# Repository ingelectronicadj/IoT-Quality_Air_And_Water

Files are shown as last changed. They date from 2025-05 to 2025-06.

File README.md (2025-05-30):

# Proyecto de Monitoreo de Calidad del Agua y del Aire con NodeMCU ESP8266

## Descripción

Este proyecto consiste en un sistema de monitoreo básico de **calidad del agua** y **calidad del aire** utilizando una placa **NodeMCU ESP8266**. Se integran sensores para medir:

- **TDS (Total de Sólidos Disueltos)** en el agua.
- **Compuestos orgánicos volátiles (TVOC)** y **dióxido de carbono equivalente (eCO2)** mediante el sensor **SGP30**.
- **Temperatura y humedad relativa** mediante un sensor **DHT11** usado para realizar compensación de la medición de TDS y por calculo realizar compensación de TVOC y eCO2 con humedad absoluta.

Los datos se envían a la plataforma en la nube **[Blynk](https://blynk.io/)** para su visualización en tiempo real desde dispositivos móviles o paneles web.

---

## Componentes del Sistema

| Componente | Descripción |
|---|---|
| **NodeMCU ESP8266** | Microcontrolador con conectividad WiFi integrada, ideal para IoT |
| **Sensor TDS (DFRobot)** | Sensor para medir sólidos disueltos totales (TDS) en agua |
| **Sensor DHT11** | Sensor digital de temperatura y humedad relativa |
| **Sensor SGP30** | Sensor de gas para medir eCO₂ (CO₂ equivalente) y TVOC |
| **Resistencia 10kΩ** | Resistencia pull-up para el pin de datos del sensor DHT11 |
| **Protoboard** | Tablero de pruebas sin soldadura para prototipado rápido |
| **Cables Dupont** | Cables macho-macho / macho-hembra para realizar conexiones entre componentes |
| **Adaptador de voltaje** | Módulo step-up o cargador que regula la salida a 5V |
| **Batería recargable** | Fuente de energía portátil para alimentar el sistema en campo |

---

## Esquemas

_A continuación se muestra el diagrama de conexiones físicas y de funcionamiento del proyecto:_

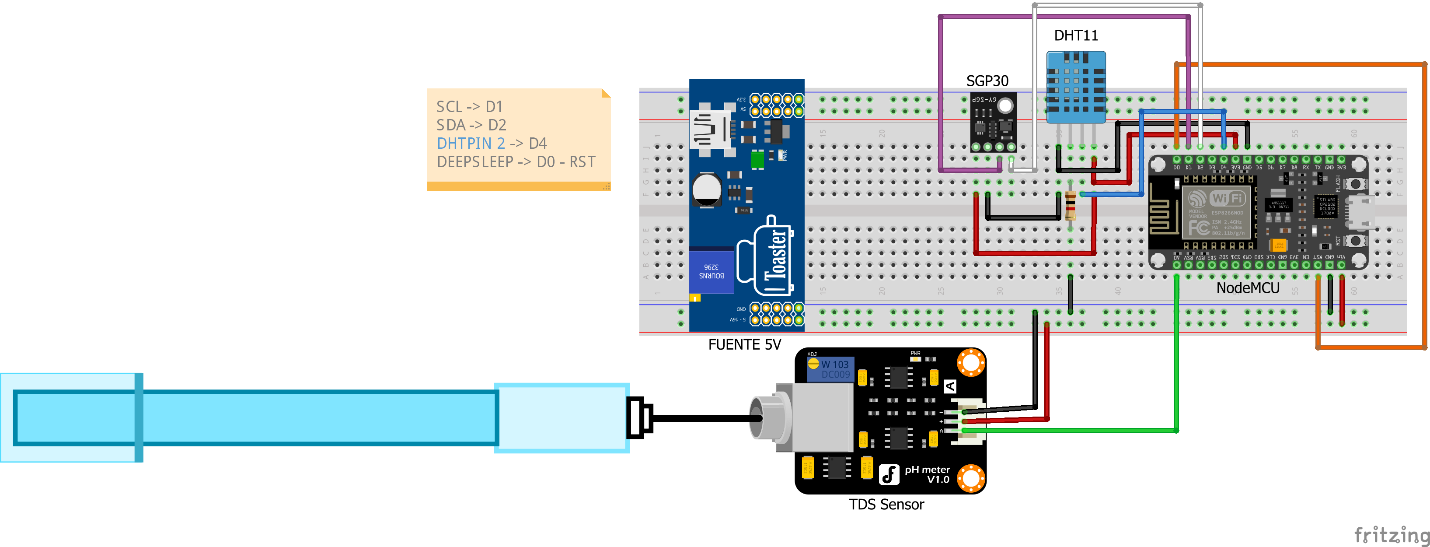
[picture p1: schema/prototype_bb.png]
Esquema de conexión


_Esquema de funcionamiento:_

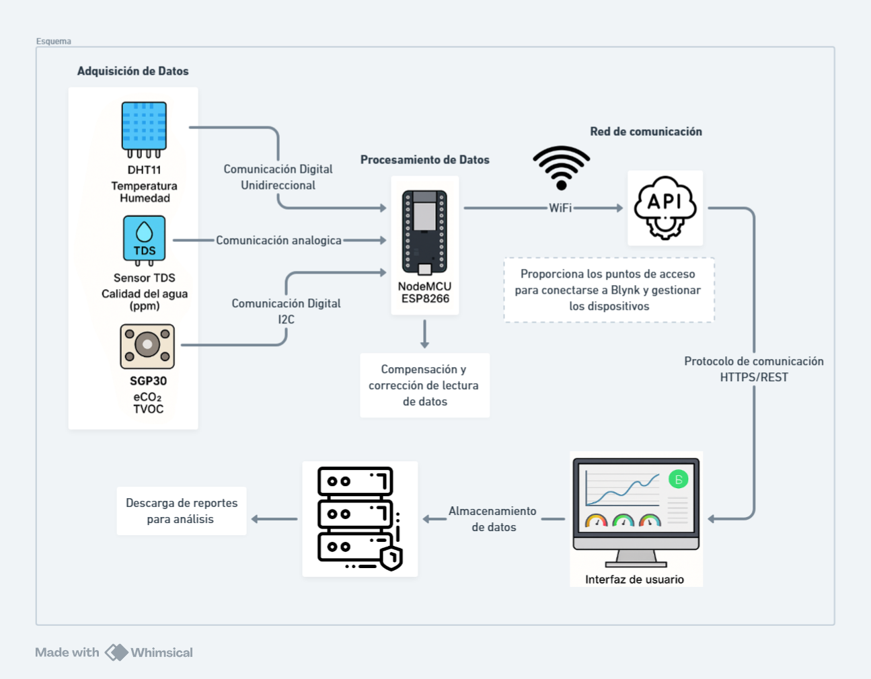
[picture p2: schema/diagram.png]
Esquema de funcionamiento


---

## Funcionamiento

Al encenderse, el sistema establece una conexión WiFi utilizando las credenciales proporcionadas. En caso de fallar la conexión tras varios intentos, el dispositivo entra en modo de bajo consumo (*deepSleep*) durante 2 minutos antes de intentar reconectarse automáticamente.

Una vez conectado, el dispositivo inicia la lectura de datos ambientales a través de los sensores conectados:

1. **Sensor DHT11 (Temperatura y Humedad):**
   - Se toma una lectura de temperatura y humedad.
   - A partir de estos datos, se calcula la humedad absoluta para compensar adecuadamente las lecturas del sensor de calidad del aire SGP30.

2. **Sensor SGP30 (Calidad del Aire):**
   - El sensor se inicializa y se verifica que esté en condiciones adecuadas para realizar mediciones.
   - Se toman varias muestras del nivel de CO₂ equivalente (eCO₂) y compuestos orgánicos volátiles totales (TVOC), promediando los valores válidos.
   - La calidad del aire se clasifica según los niveles de eCO₂ registrados:
     - **Excelente:** eCO₂ < 600 ppm
     - **Bueno:** 600 - 799 ppm
     - **Regular:** 800 - 999 ppm
     - **Pobre:** 1000 - 1499 ppm
     - **Inaceptable:** ≥ 1500 ppm

3. **Sensor TDS (Sólidos Disueltos Totales en Agua):**
   - Se realizan múltiples lecturas analógicas para obtener un promedio confiable.
   - Se calcula la conductividad eléctrica (EC) y se aplica una compensación por temperatura.
   - A partir del EC, se obtiene el valor de TDS en ppm.
   - La calidad del agua se clasifica según el nivel de TDS:
     - **Excelente:** < 300 ppm
     - **Buena:** 300 - 599 ppm
     - **Regular:** 600 - 899 ppm
     - **Pobre:** 900 - 1199 ppm
     - **Inaceptable:** ≥ 1200 ppm

4. **Envío de Datos a la Plataforma Blynk:**
   - Todos los datos obtenidos (temperatura, humedad, TDS, EC, TVOC, eCO₂ y humedad absoluta) se envían a la aplicación móvil Blynk mediante pines virtuales.
   - También se utiliza un terminal virtual para visualizar los mensajes de estado y clasificación de calidad directamente desde la app.

Finalmente, tras completar el ciclo de mediciones y envío de datos, el dispositivo entra nuevamente en modo *deepSleep* durante 2 minutos para conservar energía, repitiendo el ciclo automáticamente.

Este diseño lo convierte en un sistema eficiente para el monitoreo ambiental, ideal para implementaciones autónomas en zonas donde se requiere vigilancia constante con bajo consumo energético.

---

## Plataforma en la Nube: Blynk

Utilizamos **[Blynk](https://blynk.io/)** como plataforma IoT para visualizar los datos de los sensores en tiempo real. Blynk permite crear interfaces móviles interactivas con botones, gráficas y widgets que se comunican con el hardware de forma remota.

---

## Posibles mejoras futuras

- Cambiar el sensor DHT11 por un **DHT22** para mayor precisión.
- Añadir sensores adicionales: **pH**, **turbidez**, **temperatura del agua**.
- Enviar los datos también a una base de datos o Google Sheets.
- Agregar una pantalla OLED local para mostrar valores en sitio.
- Implementar alertas automáticas por condiciones críticas.
- Usar un **panel solar** junto con la batería recargable para operación autónoma.

---

## Licencia

Este proyecto es de código abierto y puede ser utilizado con fines educativos, personales o de investigación.

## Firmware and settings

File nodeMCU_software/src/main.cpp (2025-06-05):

// Proyecto de Monitoreo de Calidad del Agua y Aire con NodeMCU ESP8266
// Autor: Diego Javier Mena Amado
// Email: ingelectronicadj@gmail.com
// Licencia: GNU General Public License v3.0

#define BLYNK_TEMPLATE_ID "TMPL2ieIP4YG3"
#define BLYNK_TEMPLATE_NAME "Quality Water"
#define BLYNK_AUTH_TOKEN "EVXWMm138Ebxv07m-b3_FD74GFAN3gP2"
#define BLYNK_PRINT Serial

#include <Arduino.h>
#include <EEPROM.h>
#include <DHT.h>
#include <ESP8266WiFi.h>
#include <BlynkSimpleEsp8266.h>
#include <Wire.h>
#include "Adafruit_SGP30.h"

#define DHTPIN 2
#define DHTTYPE DHT11
#define TdsSensorPin A0

DHT dht(DHTPIN, DHTTYPE);
Adafruit_SGP30 sgp;
WidgetTerminal terminal(V3); // Terminal de Blynk en el pin V3

// Variables globales
float temperature = 25.0;
float humidity    = 0.0;
float tdsValue    = 0.0;
float ecValue     = 0.0;
uint16_t TVOC     = 0;
uint16_t eCO2     = 0;
uint32_t absHumidityQ16 = 0;  // Humedad absoluta en formato Q16.16 para compensación SGP30
uint32_t absH_mgm3    = 0;    // Humedad absoluta en mg/m³ (para cálculo)
float    absH_gm3     = 0.0f; // Humedad absoluta en g/m³ (para visualización y envío)
String airQualityStr;
String waterQualityStr;

// Constantes
const float VREF      = 3.28;
const int   ADC_RES   = 1024;
const float TDS_FACTOR= 0.5;
const float kValue    = 1.0;

// WiFi
char ssid[] = "Mi casa";
char pass[] = "363103631";

// ---------------- FUNCIONES ----------------

// Calcula humedad absoluta en mg/m³
uint32_t getAbsoluteHumidity_mgm3(float temperature, float humidity) {
  float absH = 216.7f * ((humidity / 100.0f) * 6.112f *
    exp((17.62f * temperature) / (243.12f + temperature)) /
    (273.15f + temperature));
  return static_cast<uint32_t>(absH * 1000.0f); // Conversión a mg/m³
}

// Conexión WiFi con reintentos
void connectToWiFi() {
  Serial.println("Intentando conectar a red WiFi de 2.4 GHz...");
  Serial.print("SSID: "); Serial.println(ssid);
  Blynk.begin(BLYNK_AUTH_TOKEN, ssid, pass);

  int wifiRetries = 0;
  while (WiFi.status() != WL_CONNECTED && wifiRetries < 20) {
    Serial.print(".");
    delay(500);
    wifiRetries++;
  }

  if (WiFi.status() != WL_CONNECTED) {
    Serial.println("\nError de conexión WiFi. Verifique que la red sea de 2.4 GHz. Reintentando en 30 segundos...");
    ESP.deepSleep(30e6);  // 30s
    // Alternativamente, podrías reiniciar el dispositivo
  } else {
    Serial.println("\nConectado al WiFi exitosamente...");
    Serial.print("Dirección IP: "); Serial.println(WiFi.localIP());

    terminal.println("Dispositivo conectado a WiFi...");
    terminal.print("IP: "); terminal.println(WiFi.localIP());
  }
}

// Lee DHT11 y actualiza compensación del SGP30
void readDHTSensor() {
  // Intento inicial sin delay
  float temp = dht.readTemperature();
  float hum  = dht.readHumidity();

  // Si no hay dato válido (>0) o NaN, espera 2s y reintenta una vez
  if (isnan(temp) || isnan(hum) || temp <= 0.0f || hum <= 0.0f) {
    terminal.println("Lectura DHT inválida, esperando 2s antes de reintentar...");
    delay(2000);
    temp = dht.readTemperature();
    hum  = dht.readHumidity();
  }

  if (!isnan(temp) && !isnan(hum) && temp > 0.0f && hum > 0.0f) {
    temperature = temp;
    humidity    = hum;

    // Calcula humedad absoluta
    absH_mgm3 = getAbsoluteHumidity_mgm3(temperature, humidity);
    absH_gm3  = absH_mgm3 / 1000.0f;  // Conversión a g/m³ para visualización

    // Muestra humedad absoluta en terminal
    terminal.print("Humedad abs: ");
    terminal.print(absH_gm3, 2);
    terminal.println(" g/m3");

    // Prepara valor Q16.16 para el SGP30
    absHumidityQ16 = absH_mgm3 * 65536ul;
    sgp.setHumidity(absHumidityQ16);
  } else {
    terminal.println("Error al leer del sensor DHT tras reintento");
  }
}

// Promedia lecturas del SGP30 con espera no bloqueante
void getAverageSGP30(uint16_t &avgECO2, uint16_t &avgTVOC, int numReadings = 5) {
  uint32_t sumECO2 = 0, sumTVOC = 0;
  int validReadings = 0, readingsDone = 0;
  unsigned long lastMillis = millis();

  while (readingsDone < numReadings) {
    if (millis() - lastMillis >= 500) {
      lastMillis = millis();
      readDHTSensor();  // Refrescar compensación cada ciclo
      if (sgp.IAQmeasure()) {
        if (sgp.eCO2 > 400 && sgp.TVOC > 10) {
          sumECO2  += sgp.eCO2;
          sumTVOC += sgp.TVOC;
          validReadings++;
        }
      }
      readingsDone++;
    }
  }

  avgECO2 = (validReadings > 0) ? sumECO2 / validReadings : sgp.eCO2;
  avgTVOC = (validReadings > 0) ? sumTVOC / validReadings : sgp.TVOC;
}

// Lectura de TDS con espera no bloqueante
void readTDS() {
  terminal.println("Sensor TDS tomando lecturas...");
  int analogSum = 0, readingsDone = 0;
  unsigned long lastMillis = millis();

  while (readingsDone < 20) {
    if (millis() - lastMillis >= 10) {
      lastMillis = millis();
      analogSum += analogRead(TdsSensorPin);
      readingsDone++;
    }
  }

  float avgAnalog = analogSum / 20.0f;
  float voltage   = avgAnalog * (VREF / ADC_RES);

  ecValue = (133.42 * voltage * voltage * voltage
           - 255.86 * voltage * voltage
           + 857.39 * voltage) * kValue;
  float compCoeff = 1.0 + 0.02 * (temperature - 25.0);
  float compEC    = ecValue / compCoeff;
  tdsValue        = compEC * TDS_FACTOR;

  terminal.print("EC: "); terminal.print(compEC, 2);
  terminal.print(" µS/cm | TDS: "); terminal.print(tdsValue, 0); terminal.println(" ppm");

  // Clasificación de la calidad del agua
  terminal.print("Calidad del Agua: ");
  if (tdsValue < 300) {
    terminal.println("EXCELENTE");
    waterQualityStr = "EXCELENTE";
  }
  else if (tdsValue < 600) {
    terminal.println("BUENA");
    waterQualityStr = "BUENA";
  }
  else if (tdsValue < 900) {
    terminal.println("REGULAR");
    waterQualityStr = "REGULAR";
  }
  else if (tdsValue < 1200) {
    terminal.println("POBRE");
    waterQualityStr = "POBRE";
  }
  else {
    terminal.println("INACEPTABLE");
    waterQualityStr = "INACEPTABLE";
  }
}

// Inicializa y calibra SGP30
void initializeSGP30() {
  if (!sgp.begin()) {
    terminal.println("Sensor SGP30 no detectado :(");
    return;
  }
  terminal.println("Sensor SGP30 precalentando...");

  bool readyToMeasure = false;
  unsigned long start = millis();
  const unsigned long maxWarm = 30000; // 30 segundos

  while (!readyToMeasure && millis() - start < maxWarm) {
    if (sgp.IAQmeasure() && sgp.eCO2 > 400 && sgp.TVOC > 10) {
      readyToMeasure = true;
      eCO2 = sgp.eCO2;
      TVOC = sgp.TVOC;
      break;
    }
    static unsigned long lastDot = 0;
    if (millis() - lastDot >= 1000) {
      lastDot = millis();
      terminal.print('.');
      terminal.flush();  // Fuerza impresión inmediata
      #ifdef BLYNK_CONNECTED
      Blynk.run();      // Mantiene sesión Blynk activa
      #endif
    }
  }

  if (readyToMeasure) {
    terminal.println("");
    terminal.println(" ► SGP30 listo para medir.");
    readDHTSensor();
    getAverageSGP30(eCO2, TVOC);
  } else {
    terminal.println(" ► Timeout. Usando última lectura.");
    sgp.IAQmeasure();
    eCO2 = sgp.eCO2;
    TVOC = sgp.TVOC;
  }

  // Muestra valores y clasifica calidad del aire
  terminal.print("eCO2: "); terminal.print(eCO2);
  terminal.print(" ppm | TVOC: "); terminal.print(TVOC);
  terminal.println(" ppb");
  terminal.print("Calidad del Aire: ");
  if (eCO2 < 600) {
    terminal.println("EXCELENTE");  
    airQualityStr = "EXCELENTE";
  }
  else if (eCO2 < 800) {
    terminal.println("BUENO");
    airQualityStr = "BUENO";
  }
  else if (eCO2 < 1000) {
    terminal.println("REGULAR");
    airQualityStr = "REGULAR";
  }
  else if (eCO2 < 1500) {
    terminal.println("POBRE");
    airQualityStr = "POBRE";
  } else {
    terminal.println("INACEPTABLE");
    airQualityStr = "INACEPTABLE";
  }
}

// Envío de datos a Blynk
void sendDataToBlynk() {
  Blynk.virtualWrite(V0, temperature);  // Temperatura (°C)
  Blynk.virtualWrite(V1, humidity);     // Humedad relativa (%)
  Blynk.virtualWrite(V2, tdsValue);     // TDS (ppm)
  Blynk.virtualWrite(V4, ecValue);      // Conductividad eléctrica (µS/cm)
  Blynk.virtualWrite(V5, TVOC);         // TVOC (ppb)
  Blynk.virtualWrite(V6, eCO2);         // eCO₂ (ppm)
  Blynk.virtualWrite(V7, absH_gm3);     // Humedad absoluta (g/m³)
  Blynk.virtualWrite(V8, airQualityStr);
  Blynk.virtualWrite(V9, waterQualityStr);
}

// ---------------- SETUP ----------------

void setup() {
  Serial.begin(9600);
  dht.begin();

  connectToWiFi();       // Conecta WiFi
  initializeSGP30();     // Precalienta y calibra SGP30
  readDHTSensor();       // Primera lectura DHT y compensación
  readTDS();             // Lectura TDS

  sendDataToBlynk();     // Envía datos a la nube

  // Mensaje final y preparación para deepSleep
  terminal.println("Entrando en deepSleep 1 min...");
  terminal.flush();
  #ifdef BLYNK_CONNECTED
  Blynk.run();           // Asegura envío de última trama
  #endif
  delay(500);            // Breve espera para terminal y Blynk

  // IMPORTANTE: para que deepSleep funcione en NodeMCU, une D0 a RST
  ESP.deepSleep(60e6);
}

void loop() {
  // No usado con deepSleep
}

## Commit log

2025-04-06 base del proyecto
    [prototype.fzz]
2025-04-12 se anade uso de temperatura para medir TVS correctamente ya que afecta la conductividad del agua, se incluyen rangos de medida segun la OMS
    [main.cpp]
2025-04-12 se anade un a mayor precision en temperatura relacionada a la mejora en conductividad del agua
2025-05-05 Envio funcional de datos, se trabaja ecuación propia para el TDS sensor
2025-05-11 se implementa deepSleep para envio de datos cada 60s, se carga libreria para el sensor de calidad del aire y se envian datos al pin virtual V3 asociado a terminal para presentar los mensajes de seria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
2025-05-11 se anade lectura de datos del sensor SGP30 para calidad del aire
2025-05-16 compensacion de lecturas para calidad del aire, estructura del codigo modular
2025-05-27 ajuste a esquema y readme del proyecto
    [prototype.fzz]
2025-05-27 se anade esquema de funcionamiento
2025-05-27 ajuste para humedad absoluta
2025-05-28 ajuste sobre la funcion para el dht, valida toma adecuada de datos o da un delay para su correcto inicio de toma de datos
    [main.cpp]
2025-05-30 ajuste sobre la funcion para conectar al wifi
2025-06-05 envio de cadenas asociadas a la pureza del aire y del agua
2025-06-05 ajuste al envio de cadenas de texto asociadas a la pureza del aire
2025-06-05 se anade un ajuste para presentarle al usuario un mensaje asociado a la limitacion wifi del esp8266 dado que solo soporta redes de 2.4Ghz
